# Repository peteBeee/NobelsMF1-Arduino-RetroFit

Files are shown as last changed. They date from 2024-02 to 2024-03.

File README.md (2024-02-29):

# History / Back Story 

I purchased an "untested" Nobels MF-1 midi foot controller on ebay, it had obviously been underwater at some point and as a result the internal control board was no longer functional.

Rather than attempt to repair it (there is a custom EPRom on the board that could be damaged), I instead decided to reuse what I could of the case and internal circuitry and team it up with an Arduino. Luckily there is already a MIDI library for the Arduino so that is one hurdle passed off the bat.

Here I will document my findings along with circuit diagrams, arduino sketch code and 3D STL files for parts where needeed. I'm not sure it will be of use to anyone but I'm quite proud of it so far.

***NOTE:*** I am building this to work with the BOSS RC505 Loopstation, it turns out this particular device has its own "quirky" requirements when receiving MIDI control (CC) instructions. It requires a CC signal of level 127 to be sent when the pedal is pressed and a second signal, level 0, to be sent when it is released.

See the Wiki for more detail:
https://github.com/peteBeee/NobelsMF1-Arduino-RetroFit/wiki

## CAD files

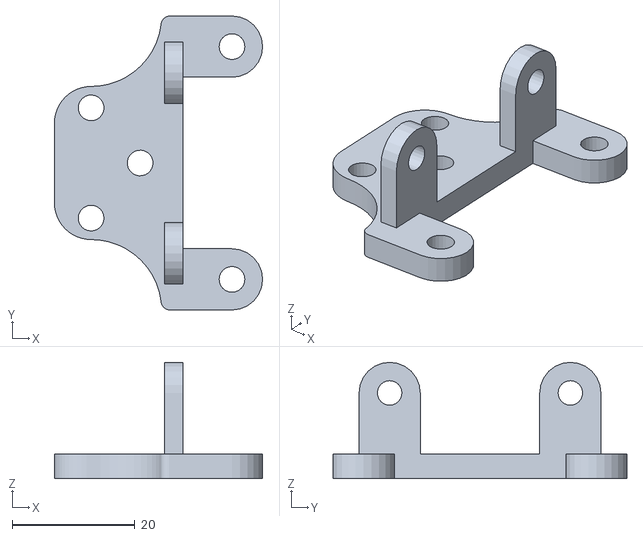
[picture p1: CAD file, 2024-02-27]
stl/USB Mount.stl
34.0 x 48.0 x 19.0

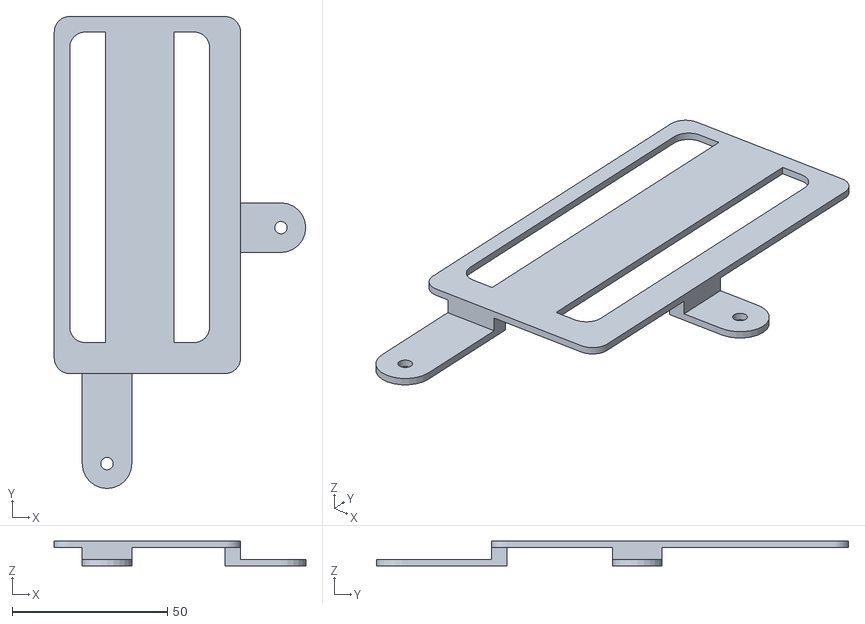
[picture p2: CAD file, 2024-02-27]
stl/arduino mount.stl
81.0 x 152.0 x 8.00

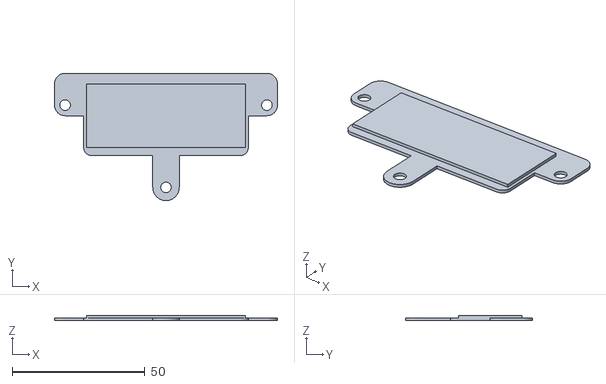
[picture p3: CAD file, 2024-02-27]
stl/MIDI Pedal Display Delete.stl
84.0 x 48.0 x 2.00

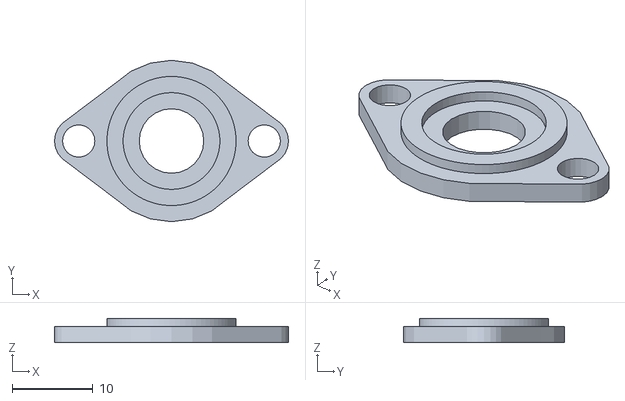
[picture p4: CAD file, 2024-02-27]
stl/Midi 2 DC.stl
29.0 x 20.0 x 3.00

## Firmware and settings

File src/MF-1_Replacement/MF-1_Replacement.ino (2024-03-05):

#include <MIDI.h>

MIDI_CREATE_INSTANCE(HardwareSerial, SERIAL_PORT_HARDWARE1, MIDI)

const int switchPins[2][6] = {
  { 26, 28, 30, 32, 34, 36 },
  { 42, 44, 46, 48, 50, 52 }
};
const int characters[17][7] = {
  { 1, 1, 1, 1, 1, 1, 0 },  //0
  { 0, 1, 1, 0, 0, 0, 0 },  //1
  { 1, 1, 0, 1, 1, 0, 1 },  //2
  { 1, 1, 1, 1, 0, 0, 1 },  //3
  { 0, 1, 1, 0, 0, 1, 1 },  //4
  { 1, 0, 1, 1, 0, 1, 1 },  //5
  { 1, 0, 1, 1, 1, 1, 1 },  //6
  { 1, 1, 1, 0, 0, 0, 0 },  //7
  { 1, 1, 1, 1, 1, 1, 1 },  //8
  { 1, 1, 1, 1, 0, 1, 1 },  //9
  { 1, 0, 0, 1, 1, 1, 0 },  //10 - C
  { 0, 0, 0, 0, 0, 0, 1 },  //11 - '-'
  { 0, 0, 0, 0, 0, 0, 0 },  //12 - blank
  { 0, 0, 0, 0, 0, 1, 0 },  //13 - top left
  { 0, 1, 0, 0, 0, 0, 0 },  //14 - top right
  { 0, 0, 0, 0, 1, 0, 0 },  //15 - bottom left
  { 0, 0, 1, 0, 0, 0, 0 },  //16 - bottom right

};
const int segmentPins[7] = { 47, 49, 41, 53, 43, 45, 51 };
const int digitPins[3] = { 31, 33, 35 };
const int dotPin = 37;
const bool showCC = true;

volatile int lastCCSent = 0;

void setup() {
  MIDI.begin(MIDI_CHANNEL_OFF);
  Serial.begin(9600);

  initSwitchPins(1);
  initSwitchPins(2);
  initDisplayPins();
  digitalWrite(dotPin, HIGH);
}

void loop() {
  // put your main code here, to run repeatedly:
  int switchNo;
  int ccNo = 0;

  if (lastCCSent > 0) {
    if(showCC){
      display(10, (lastCCSent / 10), (lastCCSent % 10), false);
    }
    else{
      showSwitchPositionFromCC(lastCCSent);
    }
  } else {
    display(12, 12, 12, false);
  }

  switchNo = readFootSwitch(1);
  if (switchNo == 0) {
    switchNo = readFootSwitch(2);
    if (switchNo > 0) {
      ccNo = CCFromSwitch(switchNo, 2);
    }
  } else {
    ccNo = CCFromSwitch(switchNo, 1);
  }

  if (ccNo == 0 && lastCCSent != 0) {
    //pedal released, send 0 to last CC
    MIDI.sendControlChange(lastCCSent, 0, 1);
    lastCCSent = 0;
  } else {
    if (ccNo != lastCCSent) {
      //Send 127 to CC, initiating the pedal press
      MIDI.sendControlChange(ccNo, 127, 1);
      lastCCSent = ccNo;
    }
  }
}

void initSwitchPins(int row) {
  pinMode(switchPins[row - 1][0], INPUT);
  pinMode(switchPins[row - 1][1], INPUT);
  for (int i = 2; i <= 6; i++) {
    pinMode(switchPins[row - 1][i], OUTPUT);
  }
}

void initDisplayPins() {
  for (int pin = 0; pin < 8; pin++) {
    pinMode(segmentPins[pin], OUTPUT);
  }
  for (int pin = 0; pin < 3; pin++) {
    pinMode(digitPins[pin], OUTPUT);
  }
  pinMode(dotPin, OUTPUT);
}

int readFootSwitch(int row) {
  int result = 0;

  //Send pins 3-6 high
  //test pin 1 after each
  //if pin1 high, set result and exit
  for (int i = 2; i <= 5; i++) {
    digitalWrite(switchPins[row - 1][i], HIGH);
    if (digitalRead(switchPins[row - 1][0]) == HIGH) result = i - 1;
    digitalWrite(switchPins[row - 1][i], LOW);
    if (result > 0) return result + 10;
  }

  //Send pins 3-4 high
  //test pin 2 after each
  //if pin2 high, set result and exit
  for (int i = 2; i <= 5; i++) {
    digitalWrite(switchPins[row - 1][i], HIGH);
    if (digitalRead(switchPins[row - 1][1]) == HIGH) result = i - 1;
    digitalWrite(switchPins[row - 1][i], LOW);
    if (result > 0) return result + 20;
  }

  return result;
}

int CCFromSwitch(int switchNo, int row) {
  switch (switchNo) {
    case 21:  //Wiredly the two boards (upper and lower are wired slightly differently - assume its related to how the original firmware worked - so button 1 can be on one of two pins)
    case 23:
      return (10 * row) + 1;
    case 14:
      return (10 * row) + 2;
    case 22:  //Wiredly the two boards (upper and lower are wired slightly differently - assume its related to how the original firmware worked - so button 3 can be on one of two pins)
    case 24:
      return (10 * row) + 3;
    case 13:
      return (10 * row) + 4;
    case 12:
      return (10 * row) + 5;
    case 11:
      return (10 * row) + 6;
    default:
      return 0;
  }
}

void display(int h, int t, int u, bool showLeadingZeros) {
  if (h == 0 && !showLeadingZeros) h = 12;
  if (h == 0 && t == 0 && !showLeadingZeros) t = 12;

  int digits[] = { h, t, u };
  for (int digit = 0; digit < 3; digit++) {
    digitalWrite(digitPins[0], LOW);
    digitalWrite(digitPins[1], LOW);
    digitalWrite(digitPins[2], LOW);


    for (int segment = 0; segment < 8; segment++) {
      digitalWrite(segmentPins[segment], characters[digits[digit]][segment] == 0 ? LOW : HIGH);
    }

    digitalWrite(digitPins[0], digit == 0 ? HIGH : LOW);
    digitalWrite(digitPins[1], digit == 1 ? HIGH : LOW);
    digitalWrite(digitPins[2], digit == 2 ? HIGH : LOW);

    delay(5);
  }
}

void showSwitchPositionFromCC(int cc) {
  if ((cc / 10) == 1) {
    switch (cc % 10) {
      case 1:
        display(13, 12, 12, false);
        break;
      case 2:
        display(14, 12, 12, false);
        break;
      case 3:
        display(12, 13, 12, false);
        break;
      case 4:
        display(12, 14, 12, false);
        break;
      case 5:
        display(12, 12, 13, false);
        break;
      case 6:
        display(12, 12, 14, false);
        break;
    }
  } else if ((cc / 10) == 2) {
    switch (cc % 10) {
      case 1:
        display(15, 12, 12, false);
        break;
      case 2:
        display(16, 12, 12, false);
        break;
      case 3:
        display(12, 15, 12, false);
        break;
      case 4:
        display(12, 16, 12, false);
        break;
      case 5:
        display(12, 12, 15, false);
        break;
      case 6:
        display(12, 12, 16, false);
        break;
    }
  } else {
    display(12, 12, 12, false);
  }
}

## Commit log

2024-02-27 Update README.md
    added link to Arduino Mega
2024-02-27 Added STL files for case parts
    [MIDI Pedal Display Delete.stl, Midi 2 DC.stl, arduino mount.stl]
2024-02-27 USB Mount STL added
    [USB Mount.stl]
2024-02-27 Fix to prevent constant sending of 0 signal
    [MF-1_Replacement.ino]
2024-03-02 Support for displaying CC number on factory LEDs
2024-03-02 Proof on concept for driving factory LED display
2024-03-04 Moved LED POC code
2024-03-05 software switch between CC display and pedal position
